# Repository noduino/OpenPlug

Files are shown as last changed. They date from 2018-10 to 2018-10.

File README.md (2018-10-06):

Noduino Open Plug
=======================================

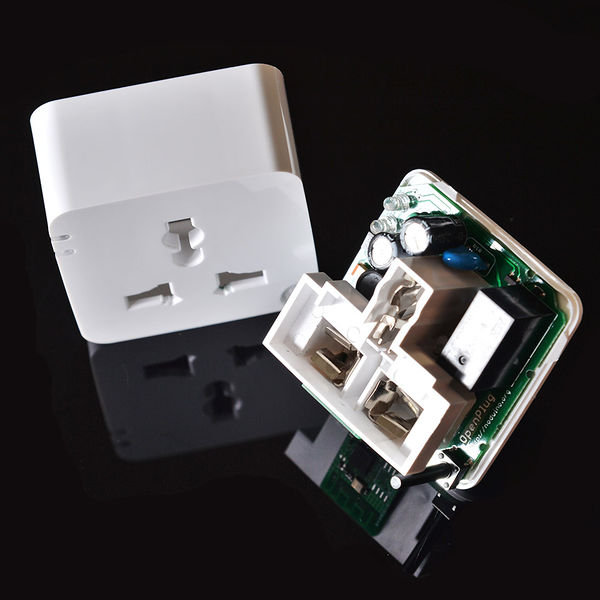
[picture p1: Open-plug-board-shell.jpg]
Noduino Open Plug Shell


[*Noduino Open Plug (OpenPlug V0.8)*](https://wiki.jackslab.org/Noduino_OpenPlug/)

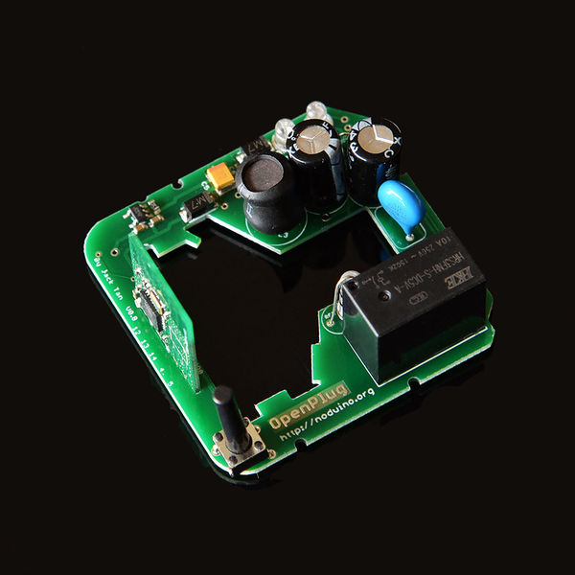
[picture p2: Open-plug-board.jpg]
Noduino Open Plug Board


[*Noduino Open Plug (OpenPlug V0.8)*](https://wiki.jackslab.org/Noduino_OpenPlug/)

Overview
-------------------

* AC 85V - 250V WiFi Smart Plug
* ESP8285 inside
* 250V 10A relay
* Shell size 53mm x 53mm x 27mm

Shell
-------------------

* https://detail.1688.com/offer/520959590805.html

WiFi Module
-------------------

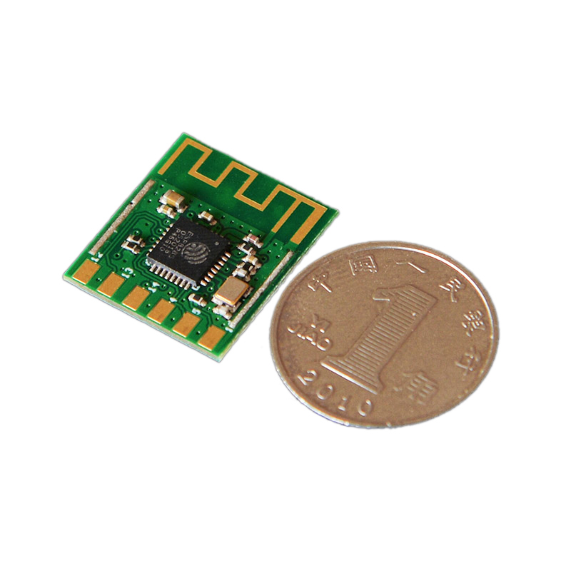
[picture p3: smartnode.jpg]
NodeC


[*Noduino NodeC WiFi Module*](https://wiki.jackslab.org/Noduino_SmartNode)

SCH
-------------------

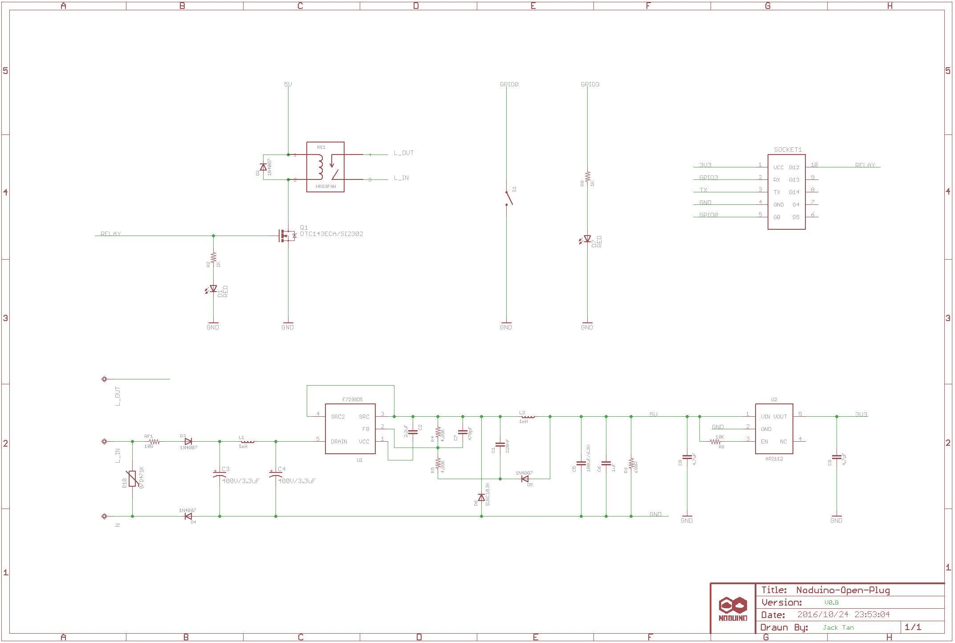
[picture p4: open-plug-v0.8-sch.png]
Noduino Open Plug sch


[*Noduino Open Plug (OpenPlug V0.8)*](https://wiki.jackslab.org/Noduino_OpenPlug/)

Layout
-------------------

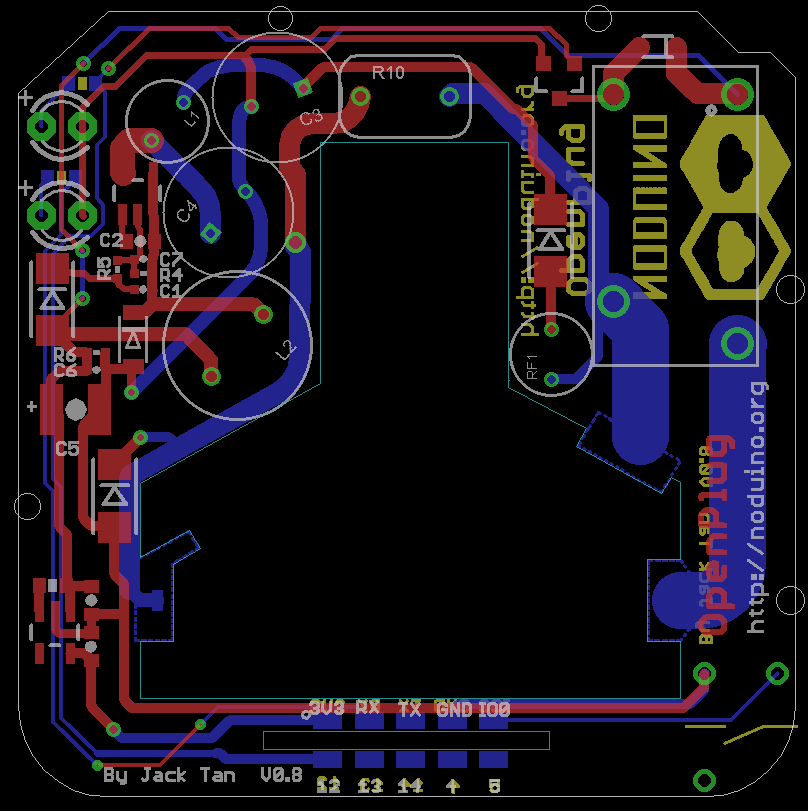
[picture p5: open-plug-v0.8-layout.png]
Noduino Open Plug layout


[*Noduino Open Plug (OpenPlug V0.8)*](https://wiki.jackslab.org/Noduino_OpenPlug/)

WiKi
-------------------

* http://wiki.jackslab.org/Noduino_OpenPlug

License Information
-------------------
The hardware is released under [Creative Commons ShareAlike 4.0 International](https://creativecommons.org/licenses/by-sa/4.0/).

Distributed as-is; no warranty is given.

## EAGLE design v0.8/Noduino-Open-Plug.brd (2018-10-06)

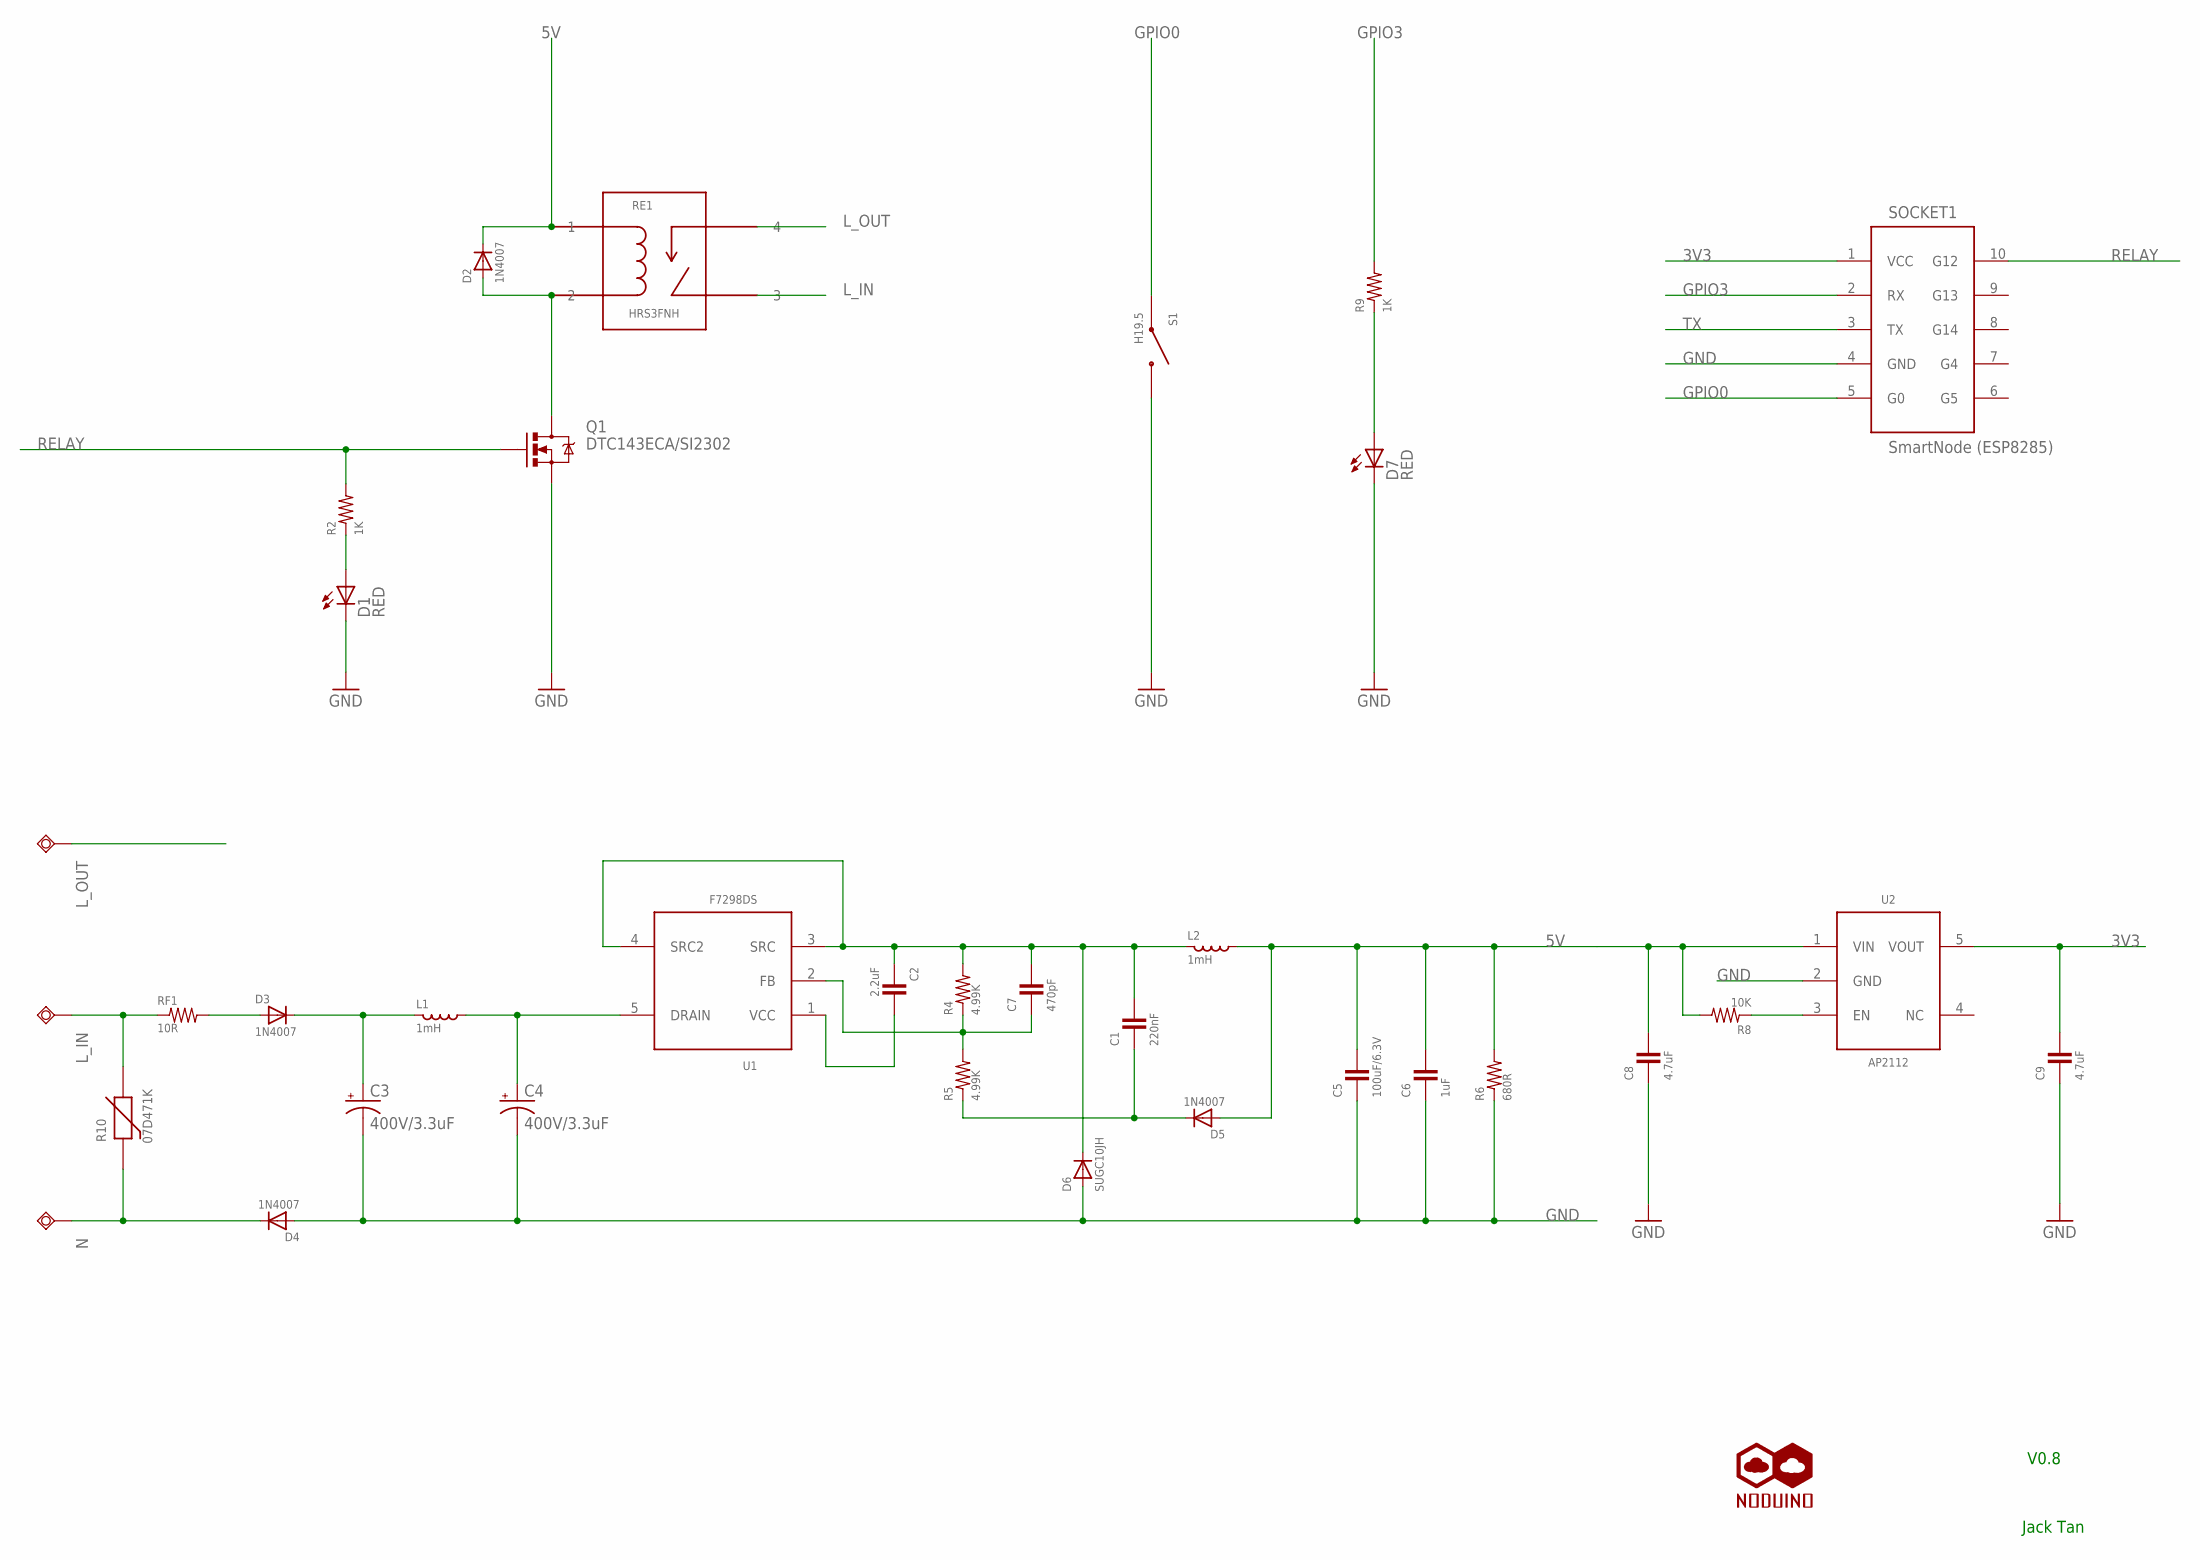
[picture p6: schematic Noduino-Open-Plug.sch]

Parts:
C1: 220nF; 0402-CAP
C2: 2.2uF; 0603-CAP
C3, C4: 400V/3.3uF; CPOL-RADIOA-3.3UF-400V
C5: 100uF/6.3V; B3528-CAP
C6: 1uF; 0402-CAP
C7: 470pF; 0402-CAP
C8, C9: 4.7uF; 0603-CAP
D1, D7: RED; LED3MM
D2: 1N4007; SOD-323
D3, D4, D5: 1N4007; DO-214
D6: SUGC10JH; SOD-123
L1: 1mH; 3-0.5-5
L2: 1mH; INDUCTOR-5-0.5
L_IN: TESTPAD50/25; 1SMD
L_OUT: TESTPAD50/25; 1SMD
N: TESTPAD50/25; 1SMD
Q1: DTC143ECA/SI2302; SOT23-3
R2, R9: 1K; 0603-RES
R4, R5: 4.99K; 0402-RES
R6: 680R; 0402-RES
R8: 10K; 0603-RES
R10: 07D471K
RE1: HRS3FNH; HKE-HRS3FN
RF1: 10R; 3-0.5-5
S1: H19.5; SWITCH-TS-037-PLUG
SOCKET1: SmartNode (ESP8285); MOD-PLUG-SOCKET
U1: F7298; SOT23-5
U2: AP2112; SOT23-5
U$1: NODUINO-LOGO-ALL; NODUINO-ALL-1

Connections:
3V3: C9.2, SOCKET1.1 (VCC), U2.5 (VOUT)
5V: C5.2, C6.2, C8.2, D2.1 (C), D5.A, L2.P$2 (X2), R6.2, R8.2, RE1.1, U2.1 (VIN)
GND: C3.P$2 (-), C4.P$2 (-), C5.1, C6.1, C8.1, C9.1, D1.K (C), D4.A, D6.A, D7.K (C), Q1.2 (S), R6.1, S1.P$1 (1), SOCKET1.4 (GND), U2.2 (GND)
GPIO0: S1.P$3 (2), SOCKET1.5 (G0)
GPIO3: R9.2, SOCKET1.2 (RX)
L_IN: L_IN.1, R10.P$2 (2), RE1.3, RF1.P$1 (1)
L_OUT: L_OUT.1, RE1.4
N: D4.C, N.1, R10.P$1 (1)
unnamed: D2.2 (A), Q1.3 (D), RE1.2
unnamed: C3.P$1 (+), D3.C, L1.P$1 (X1)
unnamed: D1.A, R2.1
unnamed: C4.P$1 (+), L1.P$2 (X2), U1.5 (DRAIN)
unnamed: C1.2, C2.1, C7.2, D6.C, L2.P$1 (X1), R4.2, U1.3 (SRC), U1.4 (SRC2)
unnamed: D3.A, RF1.P$2 (2)
unnamed: C2.2, U1.1 (VCC)
unnamed: C7.1, R4.1, R5.2, U1.2 (FB)
unnamed: C1.1, D5.C, R5.1
unnamed: R8.1, U2.3 (EN)
unnamed: D7.A, R9.1
RELAY: Q1.1 (G), R2.2, SOCKET1.10 (G12)
TX: SOCKET1.3 (TX)

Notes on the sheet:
Jack Tan
V0.8

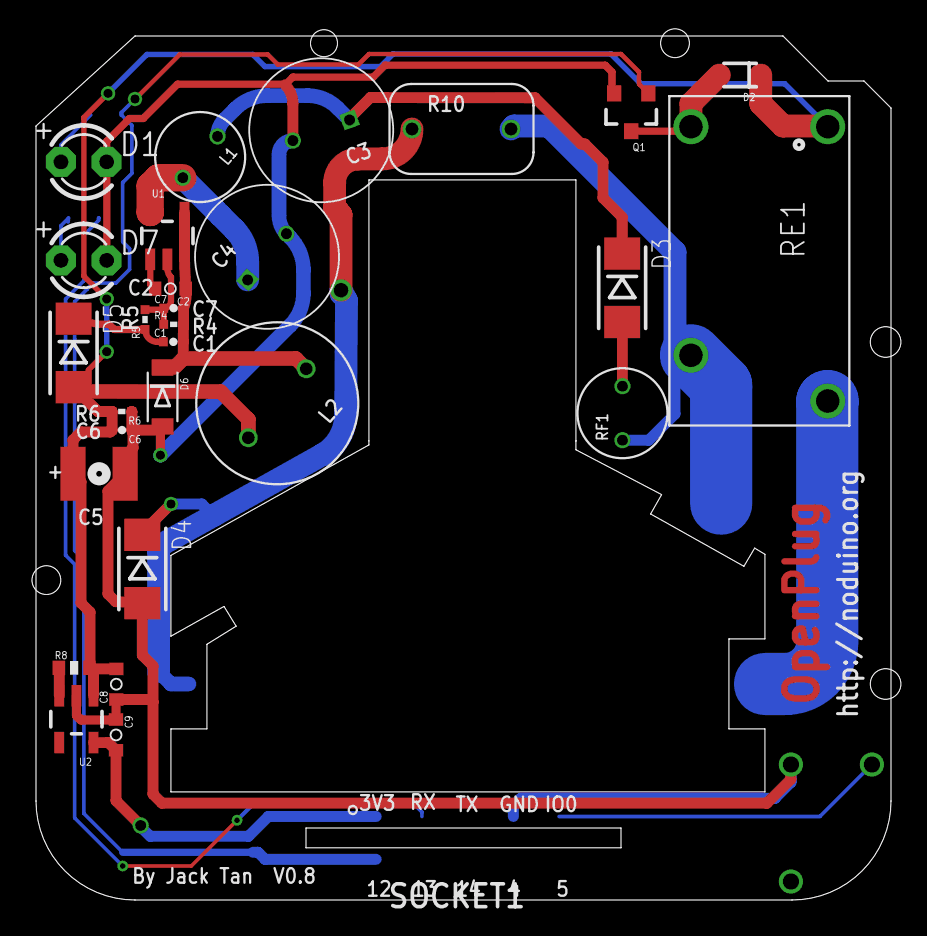
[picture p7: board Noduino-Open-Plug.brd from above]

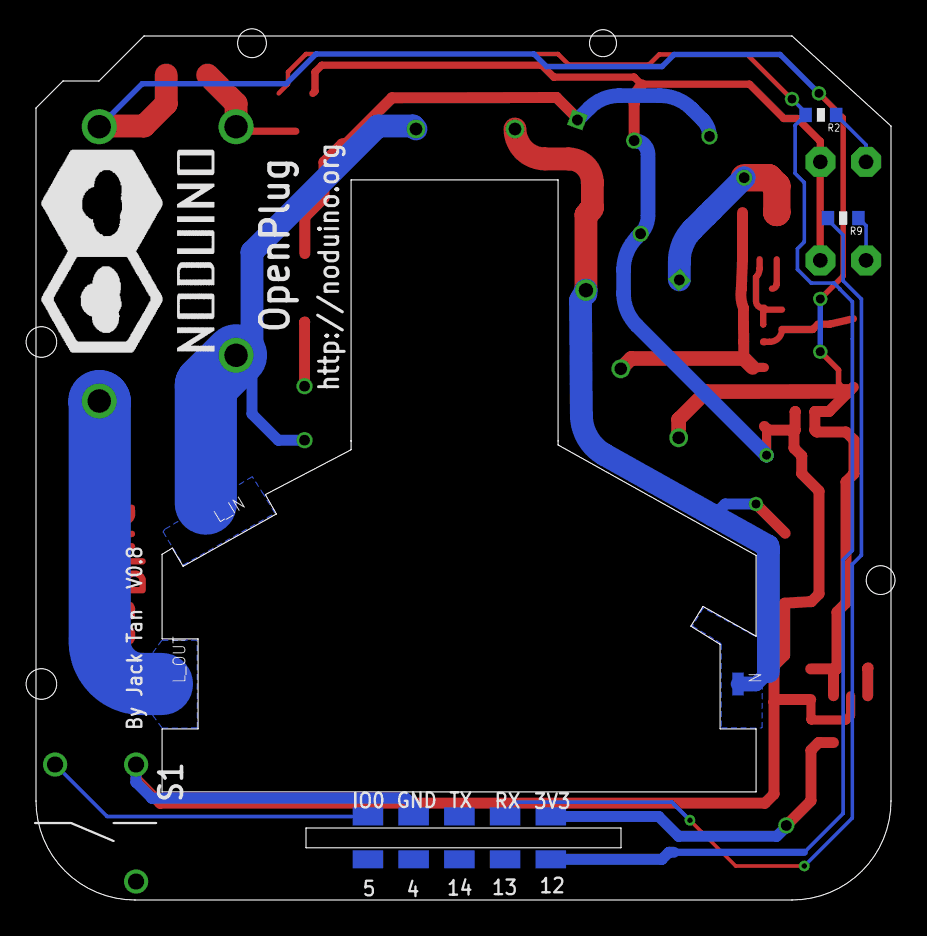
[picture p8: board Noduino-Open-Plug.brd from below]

Board: 2 copper layers, 47.5 x 48.0 mm, 36 parts (7 on the bottom side), 20 nets.

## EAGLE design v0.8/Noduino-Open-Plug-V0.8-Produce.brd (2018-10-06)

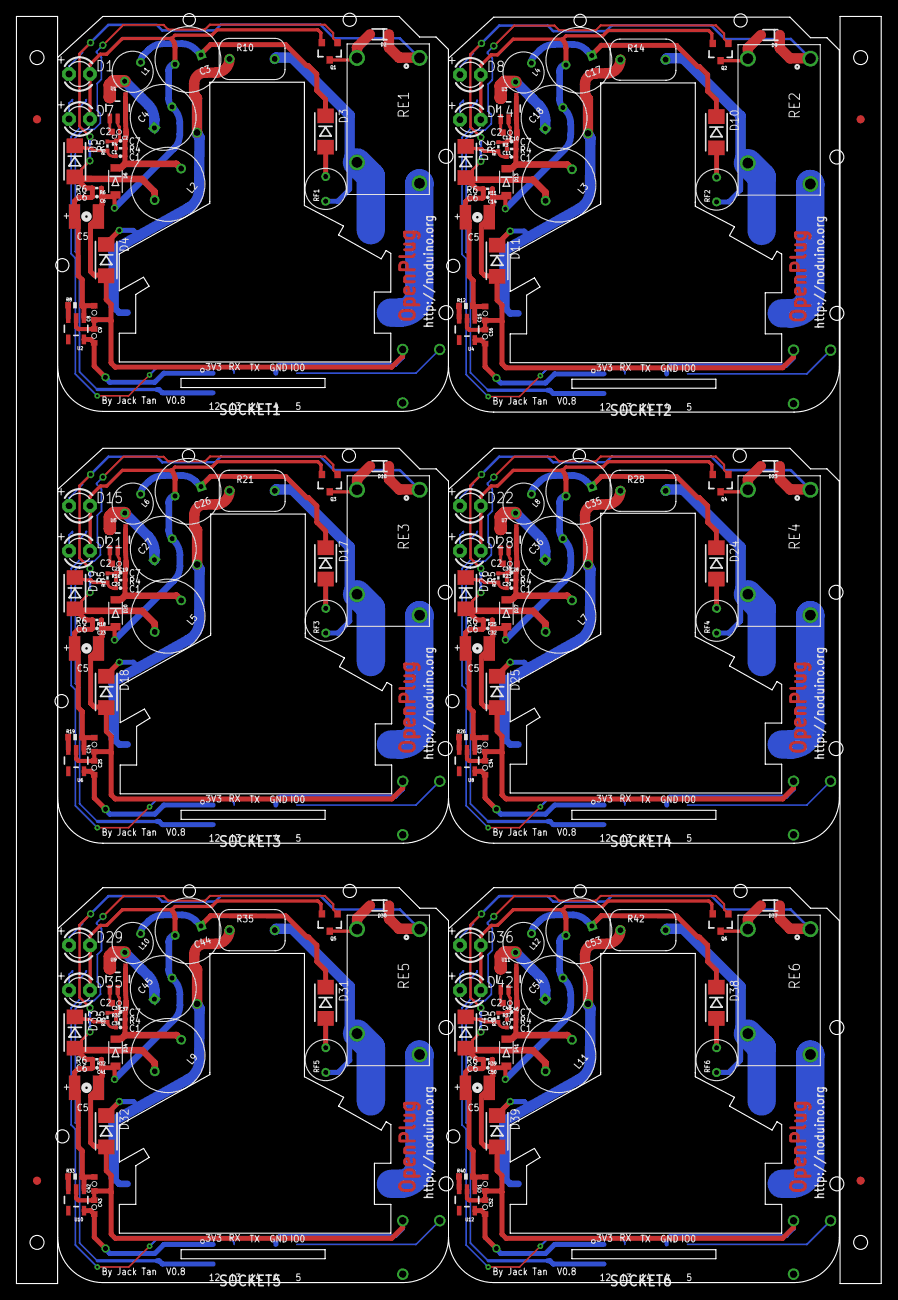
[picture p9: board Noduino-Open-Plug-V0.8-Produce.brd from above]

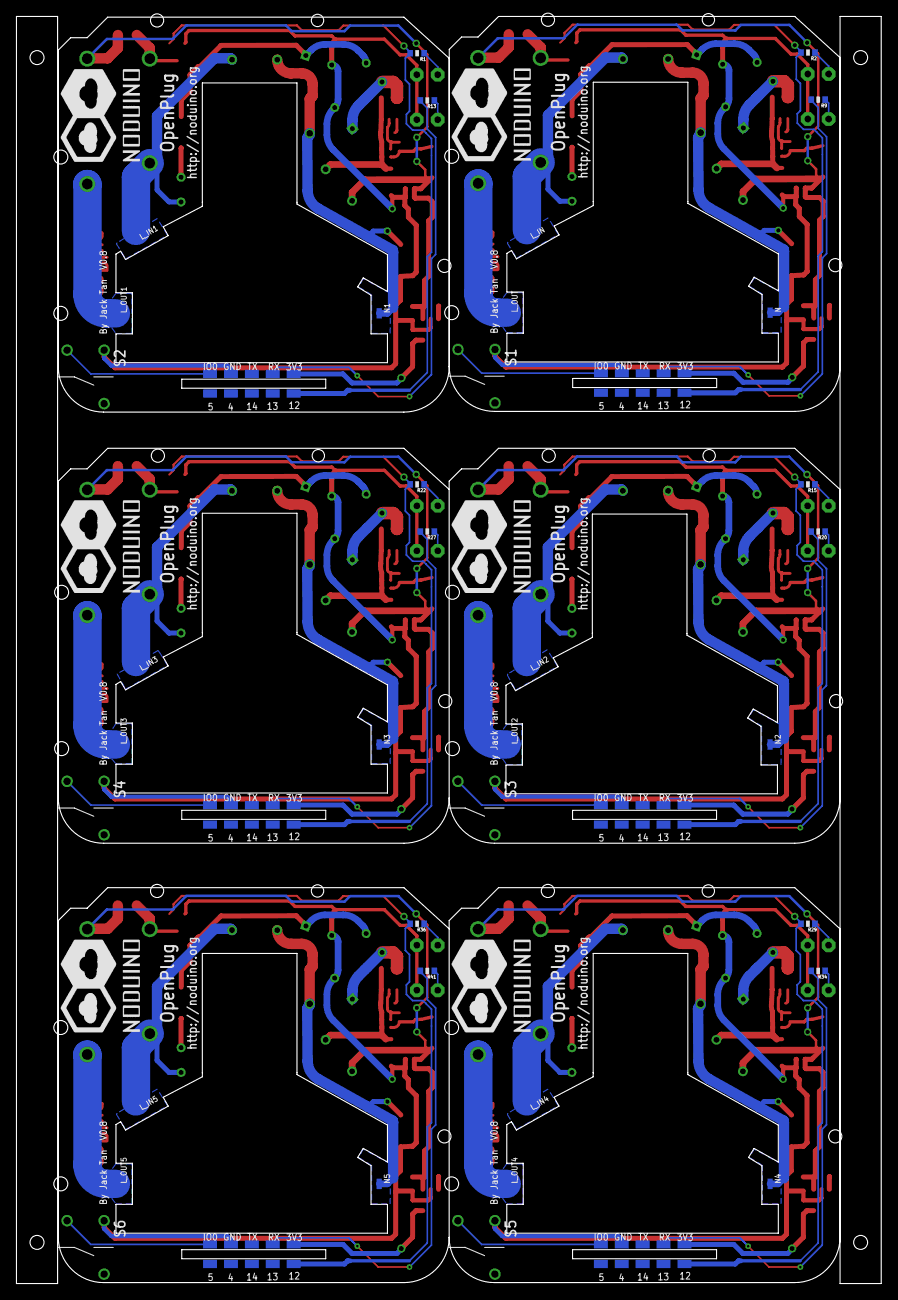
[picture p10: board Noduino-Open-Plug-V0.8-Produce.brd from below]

Board: 2 copper layers, 105.1 x 154.0 mm, 220 parts (42 on the bottom side), 120 nets.

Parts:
C1, C11, C20, C29, C38, C47: 220nF; 0402-CAP
C2, C10, C19, C28, C37, C46: 2.2uF; 0603-CAP
C3, C4, C17, C18, C26, C27, C35, C36, C44, C45, C53, C54: 400V/3.3uF; CPOL-RADIOA-3.3UF-400V
C5, C13, C22, C31, C40, C49: 100uF/6.3V; B3528-CAP
C6, C14, C23, C32, C41, C50: 1uF; 0402-CAP
C7, C12, C21, C30, C39, C48: 470pF; 0402-CAP
C8, C9, C15, C16, C24, C25, C33, C34, C42, C43, C51, C52: 4.7uF; 0603-CAP
D1, D7, D8, D14, D15, D21, D22, D28, D29, D35, D36, D42: RED; LED3MM
D2, D9, D16, D23, D30, D37: 1N4007; SOD-323
D3, D4, D5, D10, D11, D12, D17, D18, D19, D24, D25, D26, D31, D32, D33, D38, D39, D40: 1N4007; DO-214
D6, D13, D20, D27, D34, D41: T7; SOD-123
E$1, E$2, E$3, E$4: MARK-1MM
L1, L4, L6, L8, L10, L12: 1mH; 3-0.5-5
L2, L3, L5, L7, L9, L11: 1mH; INDUCTOR-5-0.5
L_IN, L_IN1, L_IN2, L_IN3, L_IN4, L_IN5: TESTPAD50/25; 1SMD
L_OUT, L_OUT1, L_OUT2, L_OUT3, L_OUT4, L_OUT5: TESTPAD50/25; 1SMD
N, N1, N2, N3, N4, N5: TESTPAD50/25; 1SMD
Q1, Q2, Q3, Q4, Q5, Q6: SI2302; SOT23-3
R1, R2, R9, R13, R15, R20, R22, R27, R29, R34, R36, R41: 1K; 0603-RES
R3, R4, R5, R7, R16, R17, R23, R24, R30, R31, R37, R38: 4.99K; 0402-RES
R6, R11, R18, R25, R32, R39: 680R; 0402-RES
R8, R12, R19, R26, R33, R40: 10K; 0603-RES
R10, R14, R21, R28, R35, R42: 07D471K
RE1, RE2, RE3, RE4, RE5, RE6: HRS3FNH; HKE-HRS3FN
RF1, RF2, RF3, RF4, RF5, RF6: 10R; 3-0.5-5
S1, S2, S3, S4, S5, S6: SWITCH-TS-037-PLUG
SOCKET1, SOCKET2, SOCKET3, SOCKET4, SOCKET5, SOCKET6: MOD-PLUG-SOCKET
U1, U3, U5, U7, U9, U11: F7298; SOT23-5
U2, U4, U6, U8, U10, U12: AP2112; SOT23-5
U$1, U$2, U$3, U$4, U$5, U$6: NODUINO-LOGO-ALL; NODUINO-ALL-1

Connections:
3V1: C16.2, SOCKET2.1, U4.5
3V2: C25.2, SOCKET3.1, U6.5
3V3: C9.2, SOCKET1.1, U2.5
3V4: C34.2, SOCKET4.1, U8.5
3V5: C43.2, SOCKET5.1, U10.5
3V6: C52.2, SOCKET6.1, U12.5
5V: C5.2, C6.2, C8.2, D2.1, D5.A, L2.P$2, R6.2, R8.2, RE1.1, U2.1
5V1: C13.2, C14.2, C15.2, D9.1, D12.A, L3.P$2, R11.2, R12.2, RE2.1, U4.1
5V2: C22.2, C23.2, C24.2, D16.1, D19.A, L5.P$2, R18.2, R19.2, RE3.1, U6.1
5V3: C31.2, C32.2, C33.2, D23.1, D26.A, L7.P$2, R25.2, R26.2, RE4.1, U8.1
5V4: C40.2, C41.2, C42.2, D30.1, D33.A, L9.P$2, R32.2, R33.2, RE5.1, U10.1
5V5: C49.2, C50.2, C51.2, D37.1, D40.A, L11.P$2, R39.2, R40.2, RE6.1, U12.1
GND: C3.P$2, C4.P$2, C5.1, C6.1, C8.1, C9.1, D1.K, D4.A, D6.A, D7.K, Q1.2, R6.1, S1.P$1, SOCKET1.4, U2.2
GND1: C13.1, C14.1, C15.1, C16.1, C17.P$2, C18.P$2, D8.K, D11.A, D13.A, D14.K, Q2.2, R11.1, S2.P$1, SOCKET2.4, U4.2
GND2: C22.1, C23.1, C24.1, C25.1, C26.P$2, C27.P$2, D15.K, D18.A, D20.A, D21.K, Q3.2, R18.1, S3.P$1, SOCKET3.4, U6.2
GND3: C31.1, C32.1, C33.1, C34.1, C35.P$2, C36.P$2, D22.K, D25.A, D27.A, D28.K, Q4.2, R25.1, S4.P$1, SOCKET4.4, U8.2
GND4: C40.1, C41.1, C42.1, C43.1, C44.P$2, C45.P$2, D29.K, D32.A, D34.A, D35.K, Q5.2, R32.1, S5.P$1, SOCKET5.4, U10.2
GND5: C49.1, C50.1, C51.1, C52.1, C53.P$2, C54.P$2, D36.K, D39.A, D41.A, D42.K, Q6.2, R39.1, S6.P$1, SOCKET6.4, U12.2
GPIO0: S1.P$3, SOCKET1.5
GPIO1: R13.2, SOCKET2.2
GPIO2: S2.P$3, SOCKET2.5
GPIO3: R9.2, SOCKET1.2
GPIO4: R20.2, SOCKET3.2
GPIO5: S3.P$3, SOCKET3.5
GPIO6: R27.2, SOCKET4.2
GPIO7: S4.P$3, SOCKET4.5
GPIO8: R34.2, SOCKET5.2
GPIO9: S5.P$3, SOCKET5.5
GPIO10: R41.2, SOCKET6.2
GPIO11: S6.P$3, SOCKET6.5
L_IN: L_IN.1, R10.P$2, RE1.3, RF1.P$1
L_IN1: L_IN1.1, R14.P$2, RE2.3, RF2.P$1
L_IN2: L_IN2.1, R21.P$2, RE3.3, RF3.P$1
L_IN3: L_IN3.1, R28.P$2, RE4.3, RF4.P$1
L_IN4: L_IN4.1, R35.P$2, RE5.3, RF5.P$1
L_IN5: L_IN5.1, R42.P$2, RE6.3, RF6.P$1
L_OUT: L_OUT.1, RE1.4
L_OUT1: L_OUT1.1, RE2.4
L_OUT2: L_OUT2.1, RE3.4
L_OUT3: L_OUT3.1, RE4.4
L_OUT4: L_OUT4.1, RE5.4
L_OUT5: L_OUT5.1, RE6.4
N: D4.C, N.1, R10.P$1
N1: D11.C, N1.1, R14.P$1
N2: D18.C, N2.1, R21.P$1
N3: D25.C, N3.1, R28.P$1
N4: D32.C, N4.1, R35.P$1
N5: D39.C, N5.1, R42.P$1
unnamed: D8.A, R1.1
unnamed: D2.2, Q1.3, RE1.2
unnamed: C3.P$1, D3.C, L1.P$1
unnamed: D1.A, R2.1
unnamed: C4.P$1, L1.P$2, U1.5
unnamed: C1.2, C2.1, C7.2, D6.C, L2.P$1, R4.2, U1.3, U1.4
unnamed: D3.A, RF1.P$2
unnamed: D9.2, Q2.3, RE2.2
unnamed: C17.P$1, D10.C, L4.P$1
unnamed: C2.2, U1.1
unnamed: C7.1, R4.1, R5.2, U1.2
unnamed: C1.1, D5.C, R5.1
unnamed: R8.1, U2.3
unnamed: D7.A, R9.1
unnamed: C18.P$1, L4.P$2, U3.5
unnamed: C10.1, C11.2, C12.2, D13.C, L3.P$1, R3.2, U3.3, U3.4
unnamed: D10.A, RF2.P$2
unnamed: C10.2, U3.1
unnamed: C12.1, R3.1, R7.2, U3.2
unnamed: C11.1, D12.C, R7.1
unnamed: R12.1, U4.3
unnamed: D14.A, R13.1
unnamed: D15.A, R15.1
unnamed: D16.2, Q3.3, RE3.2
unnamed: C26.P$1, D17.C, L6.P$1
unnamed: C27.P$1, L6.P$2, U5.5
unnamed: C19.1, C20.2, C21.2, D20.C, L5.P$1, R16.2, U5.3, U5.4
unnamed: D17.A, RF3.P$2
unnamed: C19.2, U5.1
unnamed: C21.1, R16.1, R17.2, U5.2
unnamed: C20.1, D19.C, R17.1
unnamed: R19.1, U6.3
unnamed: D21.A, R20.1
unnamed: D22.A, R22.1
unnamed: D23.2, Q4.3, RE4.2
unnamed: C35.P$1, D24.C, L8.P$1
unnamed: C36.P$1, L8.P$2, U7.5
unnamed: C28.1, C29.2, C30.2, D27.C, L7.P$1, R23.2, U7.3, U7.4
unnamed: D24.A, RF4.P$2
unnamed: C28.2, U7.1
unnamed: C30.1, R23.1, R24.2, U7.2
unnamed: C29.1, D26.C, R24.1
unnamed: R26.1, U8.3
unnamed: D28.A, R27.1
unnamed: D29.A, R29.1
unnamed: D30.2, Q5.3, RE5.2
unnamed: C44.P$1, D31.C, L10.P$1
unnamed: C45.P$1, L10.P$2, U9.5
unnamed: C37.1, C38.2, C39.2, D34.C, L9.P$1, R30.2, U9.3, U9.4
unnamed: D31.A, RF5.P$2
unnamed: C37.2, U9.1
unnamed: C39.1, R30.1, R31.2, U9.2
unnamed: C38.1, D33.C, R31.1
unnamed: R33.1, U10.3
unnamed: D35.A, R34.1
unnamed: D36.A, R36.1
unnamed: D37.2, Q6.3, RE6.2
unnamed: C53.P$1, D38.C, L12.P$1
unnamed: C54.P$1, L12.P$2, U11.5
unnamed: C46.1, C47.2, C48.2, D41.C, L11.P$1, R37.2, U11.3, U11.4
unnamed: D38.A, RF6.P$2
unnamed: C46.2, U11.1
unnamed: C48.1, R37.1, R38.2, U11.2
unnamed: C47.1, D40.C, R38.1
unnamed: R40.1, U12.3
unnamed: D42.A, R41.1
RELAY: Q1.1, R2.2, SOCKET1.10
RELAY1: Q2.1, R1.2, SOCKET2.10
RELAY2: Q3.1, R15.2, SOCKET3.10
RELAY3: Q4.1, R22.2, SOCKET4.10
RELAY4: Q5.1, R29.2, SOCKET5.10
RELAY5: Q6.1, R36.2, SOCKET6.10

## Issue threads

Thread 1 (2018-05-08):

openplug power supply

ralf33609, 2018-05-08:
I've seen the schematic of openplug on jackslab.org with integrated circuit U1 F7298DS in sot23-5 housing. Can you tell me the manufacturer or better a datasheet of that ic?

Abhesheksh, 2020-02-15:
Hi, did you ever get that datasheet? Or anything about that IC?

ralf33609, 2020-02-19:
Unfortunately not. P.S. Sorry for late answer.

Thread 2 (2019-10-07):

OpenPlug BOM List

joaocarlosss84, 2019-10-07:
Hi,
Where can I find the complete Bill Of Materials (BOM) list for OpenPlug.
I would like to build the power supply and test it.
And where can I buy the NodeC module?

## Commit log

2018-10-06 add the sch and layout files
    [Noduino-Open-Plug-V0.8-Produce.brd, Noduino-Open-Plug.brd, Noduino-Open-Plug.sch]
2018-10-06 add the gerber files for mass producing
